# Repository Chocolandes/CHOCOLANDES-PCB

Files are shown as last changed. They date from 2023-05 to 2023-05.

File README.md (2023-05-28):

# CHOCOLANDES-PCB

In this repository you will find the gerber files ready for the Chocolandes PCB fabrication and the eagle files with which the pcb was designed.

Here are the components and connections contained in the instrumentacion.sch file:

## Material's list:
### In this project we use two ESP32 microcontrollers. One is dedicated to the stepper motor movement (ESP-MOT) and the other is in charge of all the other functionalities (ESP-MAIN).
### L293D
Dual DC motor driver 

* In1: D33 ESP-MAIN
* In2: D32 ESP-MAIN
* Out1: Red wire motor pump
* Out2: Black wire motor pump
* En1: 5V
* VCC: 5V
* Vss: 12V
* Pin 4 y 5: GND

### HX711
Load cell ADC converter

* E+: Red
* E-: Black
* A+: Withe
* A-: Green
* Dt: D26 ESP-MAIN
* Sck: D27 ESP-MAIN
* Vcc: 5V

### A4988
Stepper motor driver 
* Dir: D19  ESP-MOT
* Step: D18  ESP-MOT
* Enable: D5  ESP-MOT
* Vdd: 5V
* Reset & Sleep Are connected between them
* 2B: Black 
* 2A: Green
* 1A: Blue
* 1B: Red
* Vmot: External power (12V)

### NEMA 17HS4401s
Stepper motor with 1.8° resolution
* Black: 2B
* Green: 2A
* Blue: 1A
* Red: 1B
### HC020P
* Vdd: 5V
* Data: D34 ESP-MOT
### DS18B20
* Vdd: 5V
* Data: D13 ESP-MAIN
### Motor Pump
* Red: Out1 L293D
* Black: Out2 L293D
### Load Cell
* Red: E+
* Black: E-
* Withe: A+
* Green: A-

### ESP-MAIN
* D33: In1 L293D
* D32: In2 L293D
* D26: Dt HX711
* D27: Sck HX711
* D13: Data DS18B20
### ESP-MOT
* D5: Enable A4988
* D19: DIR A4988
* D18: STEP A4988
* D34: Data HC020P

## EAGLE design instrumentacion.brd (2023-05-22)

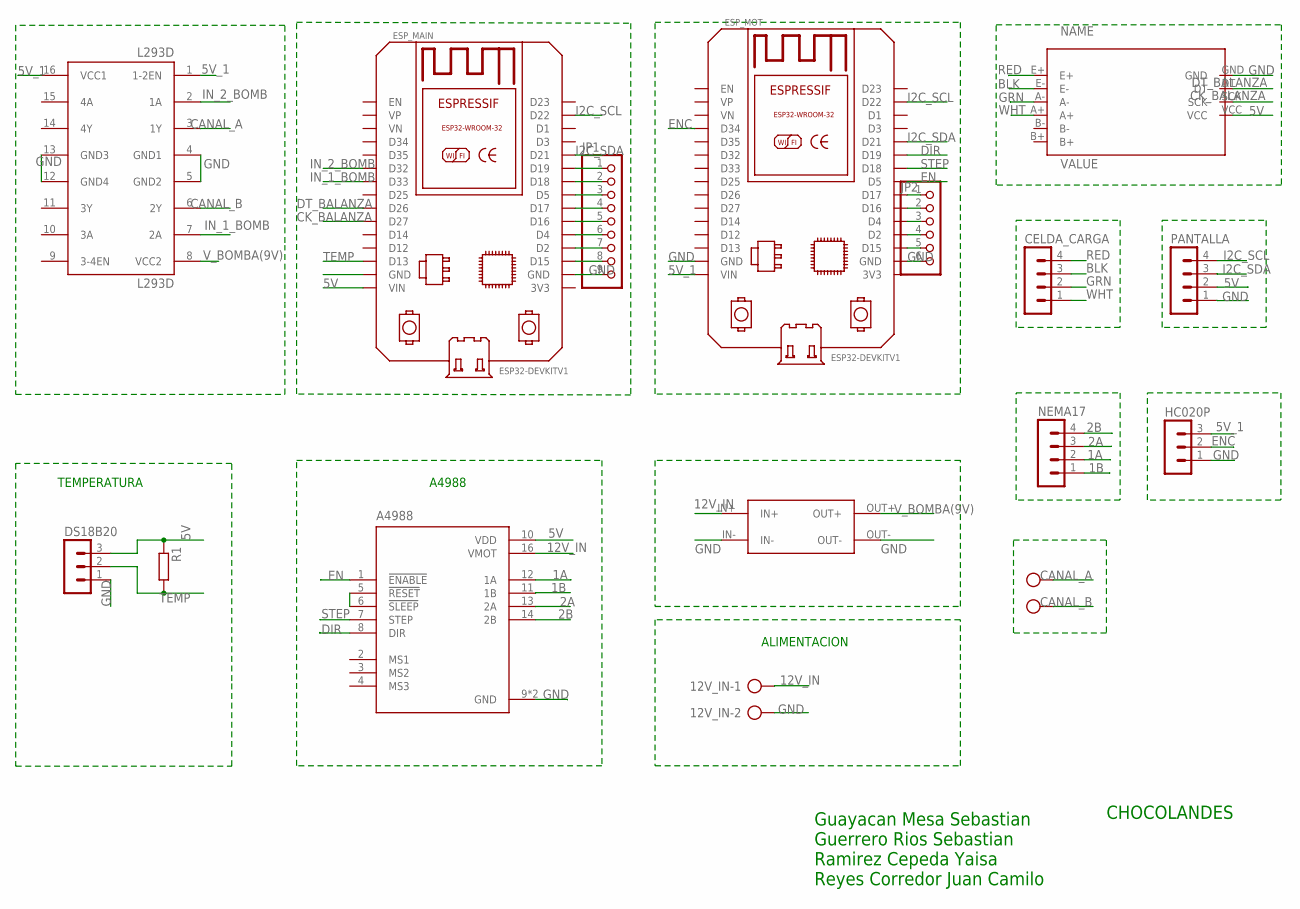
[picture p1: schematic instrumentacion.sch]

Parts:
12V_IN: SMKDSP_1,5/2
A4988: A4988_STEPPER_MOTOR_DRIVER_CARRIER; MODULE_A4988_STEPPER_MOTOR_DRIVER_CARRIER
BOMBA: SMKDSP_1,5/2
CELDA_CARGA: MA04-1
DS18B20: MA03-1
ESP_MAIN: ESP32DEVKITV1; ESP32-DEVKITV1
ESP_MOT: ESP32DEVKITV1; ESP32-DEVKITV1
HC020P: MA03-1
HX711: HX711A; HX711
JP1: PINHD-1X9; 1X09
JP2: PINHD-1X6; 1X06
L293D: L293D; DIL16
NEMA17: MA04-1
PANTALLA: MA04-1
R1: R-EU_0204/7; 0204/7
U$1: LM2596_3A; LM259_PADS

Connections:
1A: A4988.12 (1A), NEMA17.2
1B: A4988.11 (1B), NEMA17.1
2A: A4988.13 (2A), NEMA17.3
2B: A4988.14 (2B), NEMA17.4
5V: A4988.10 (VDD), DS18B20.3, ESP_MAIN.VIN, HX711.VCC, PANTALLA.2, R1.1
5V_1: ESP_MOT.VIN, HC020P.3, L293D.1 (1-2EN), L293D.16 (VCC1)
12V_IN: 12V_IN.1, A4988.16 (VMOT), U$1.IN+
BLK: CELDA_CARGA.3, HX711.E-
CANAL_A: BOMBA.1, L293D.3 (1Y)
CANAL_B: BOMBA.2, L293D.6 (2Y)
CK_BALANZA: ESP_MAIN.D27, HX711.SCK
DIR: A4988.8 (DIR), ESP_MOT.D19
DT_BALANZA: ESP_MAIN.D26, HX711.DT
EN: A4988.1 (!ENABLE), ESP_MOT.D5
ENC: ESP_MOT.D34, HC020P.2
GND: 12V_IN.2, A4988.9 (GND), A4988.15 (GND), DS18B20.1, ESP_MAIN.GND, ESP_MAIN.GND@1 (GND), ESP_MOT.GND, ESP_MOT.GND@1 (GND), HC020P.1, HX711.GND, JP1.9, JP2.6, L293D.4 (GND1), L293D.5 (GND2), L293D.12 (GND4), L293D.13 (GND3), PANTALLA.1, U$1.IN-, U$1.OUT-
GRN: CELDA_CARGA.2, HX711.A-
I2C_SCL: ESP_MAIN.D22, ESP_MOT.D22, PANTALLA.4
I2C_SDA: ESP_MAIN.D21, ESP_MOT.D21, PANTALLA.3
IN_1_BOMB: ESP_MAIN.D33, L293D.7 (2A)
IN_2_BOMB: ESP_MAIN.D32, L293D.2 (1A)
unnamed: ESP_MAIN.D19, JP1.1
unnamed: ESP_MAIN.D18, JP1.2
unnamed: ESP_MAIN.D5, JP1.3
unnamed: ESP_MAIN.D17, JP1.4
unnamed: ESP_MAIN.D16, JP1.5
unnamed: ESP_MAIN.D4, JP1.6
unnamed: A4988.5 (!RESET), A4988.6 (!SLEEP)
unnamed: ESP_MAIN.D2, JP1.7
unnamed: ESP_MAIN.D15, JP1.8
unnamed: ESP_MOT.D17, JP2.1
unnamed: ESP_MOT.D16, JP2.2
unnamed: ESP_MOT.D4, JP2.3
unnamed: ESP_MOT.D2, JP2.4
unnamed: ESP_MOT.D15, JP2.5
RED: CELDA_CARGA.4, HX711.E+
STEP: A4988.7 (STEP), ESP_MOT.D18
TEMP: DS18B20.2, ESP_MAIN.D13, R1.2
V_BOMBA(9V): L293D.8 (VCC2), U$1.OUT+
WHT: CELDA_CARGA.1, HX711.A+

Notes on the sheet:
TEMPERATURA
ALIMENTACION
A4988
CHOCOLANDES
Guayacan Mesa Sebastian Guerrero Rios Sebastian Ramirez Cepeda Yaisa Reyes Corredor Juan Camilo

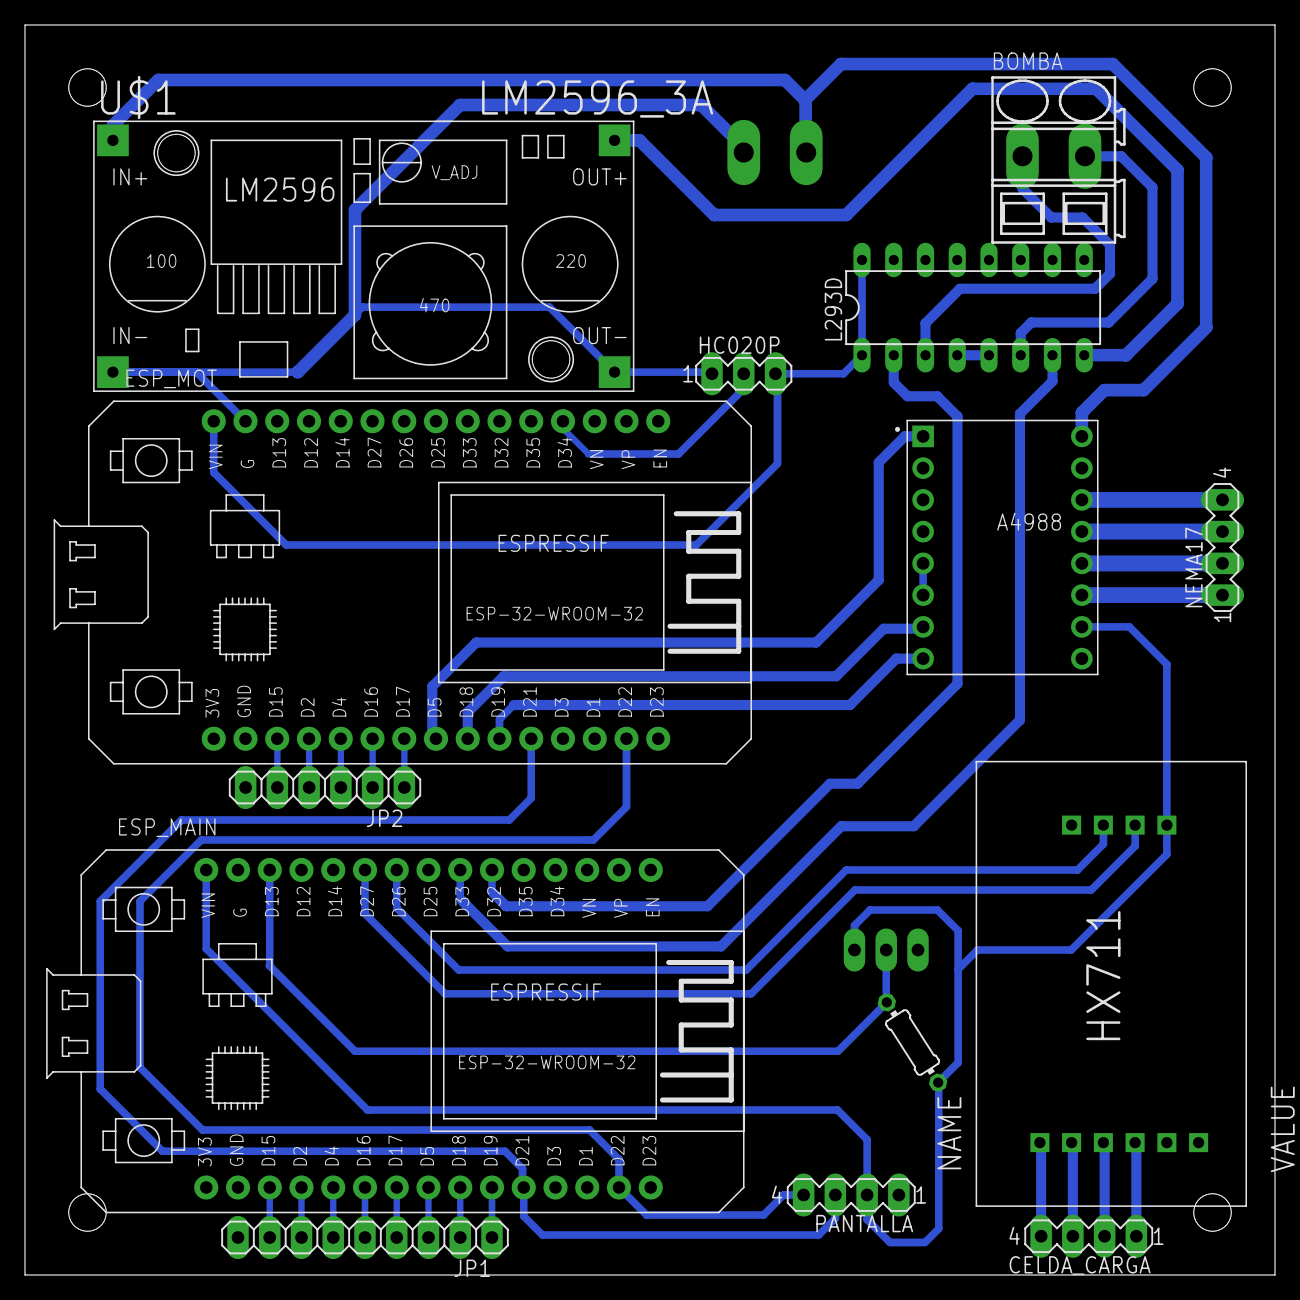
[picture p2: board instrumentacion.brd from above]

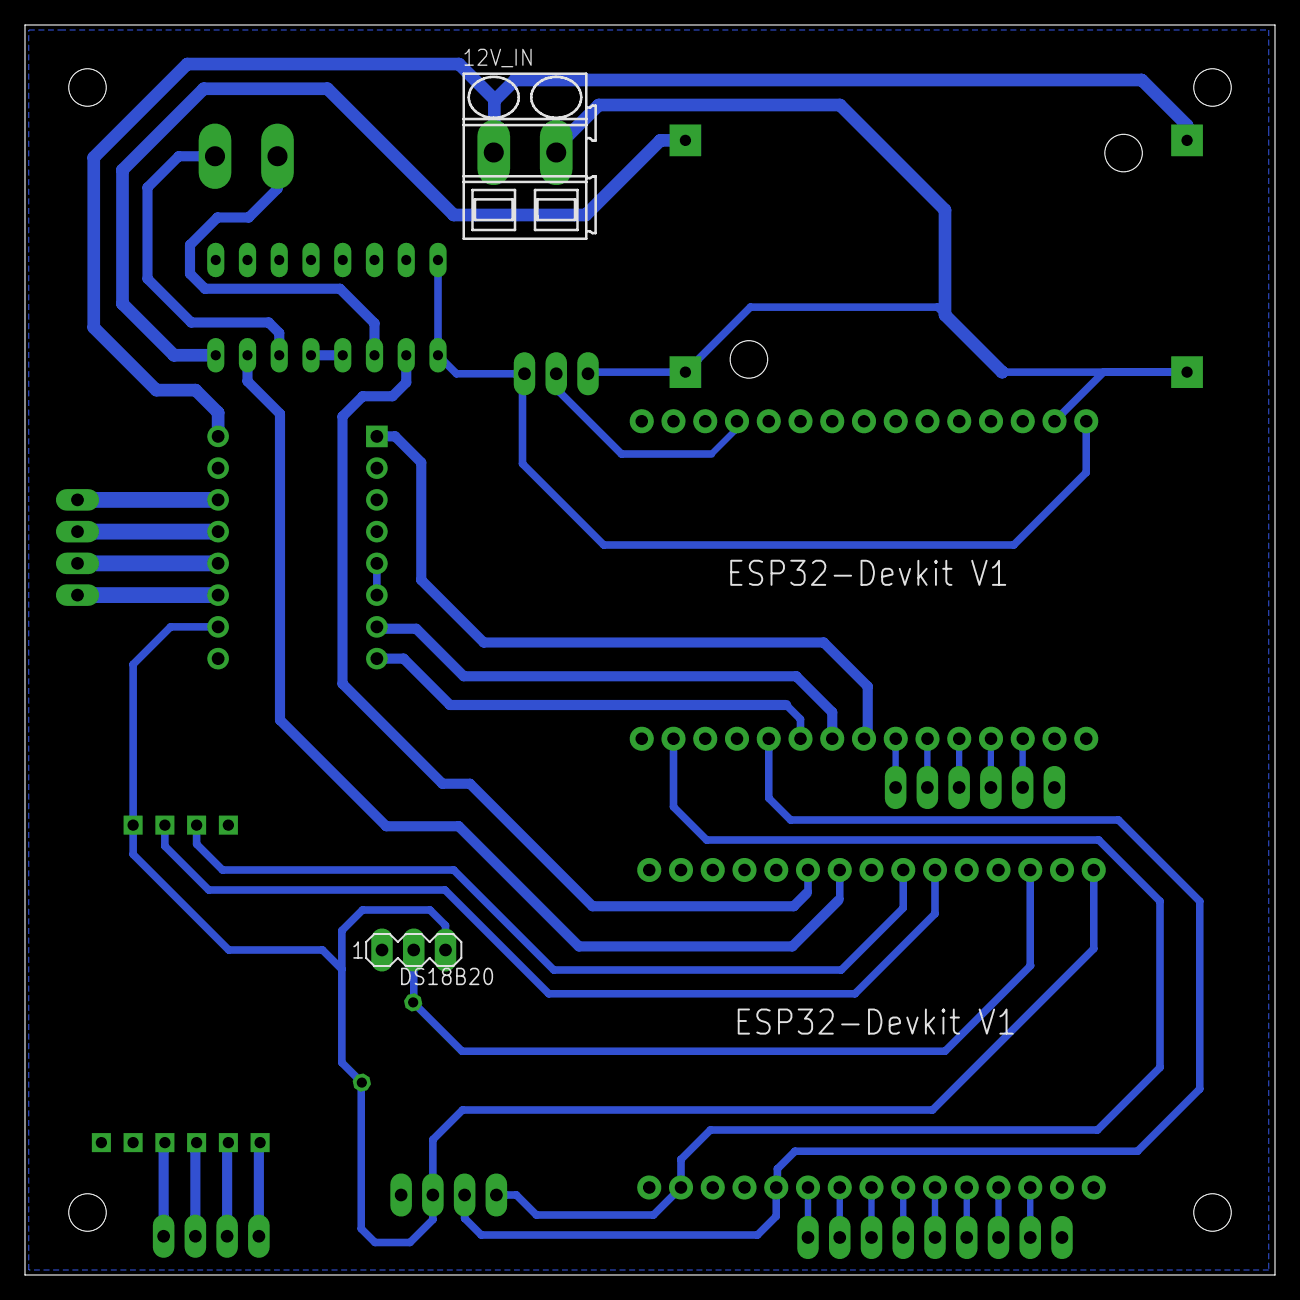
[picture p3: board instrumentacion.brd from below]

Board: 2 copper layers, 100.0 x 100.0 mm, 16 parts (2 on the bottom side), 40 nets.
